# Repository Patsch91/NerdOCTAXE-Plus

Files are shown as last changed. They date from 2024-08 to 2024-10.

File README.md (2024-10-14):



The NerdOCTAXE+ is a 8-Asic version of the [NerdQAxe+](https://github.com/shufps/qaxe) with [Nerdminer](https://github.com/BitMaker-hub/NerdMiner_v2) / [Nerdaxe](https://github.com/BitMaker-hub/NerdAxeUltra) Display and is running the [BitAxe](https://github.com/skot/bitaxe) Firmware as its Core.

It runs standalone and uses 8 ASICs of type BM1368 to achieve an average Hashrate of ~5Th/s at ~100Watts (approx. 110Watt at the wall... i have not measured it yet)



Highlights:

- uses the NerdAxe / NerdMiner display
- 3-Phase Buck  // The TPS could handle 4 Phases... currently thinking of changing it to 4-Phase design
- Standalone, no Raspberry Pi or other PC needed
- AxeOS with improvements and enhancements - slightly modified version of [ESP-Miner-NerdQAxe+](https://github.com/shufps/ESP-Miner-NerdQAxePlus)
  - Influx DB support
  - Better charting (10m, 1h, 1d), data doesn't get lost on Web UI reloads 
  - ASIC clock and voltage adjustable without reboot
  - Stratum client stability improvements (TCP timeouts)

The NerdOCTAXE+ runs with a modified version of the AxeOS: https://github.com/Patsch91/ESP-Miner-NerdOctaxePlus 

-------------------------------

# Build

**DISCLAIMER:** This device is an *advanced* build and partly WIP. To get 8 Asics soldered properly *can* be very hard and frustrating if you are not used to soldering Asics or soldering in general. Using that amount of power, this device isn't a toy and you should know what you are doing - stay safe!

The first prototype is running a little bit high on Temps: Buck at ~80°C and Asics about 60-70°C (so for now I used a rather unconventional way of additional cooling glueing some -many- cheapo small heatsinks directly onto the PCB which dropped the buck Temp to nice 50°C and Asics about 50-60°C)

**PCB:** For example with the JLC Plugin for Kicad you can export the files out of Kicad to order directly from JLCPCB or any other PCB-Manufacturer

**BOM:** You can directly upload the .csv in this repo to Digikey (watch out - this is still a bit of WIP - you could delete the heatsink for example, which is actually in the BOM, but I am currently testing other ones which I will add later on). You will have to order the Lilygo T-Display S3 seperately.

**HEATSINKS:** Cooling is WIP. For the actual first Prototype I used 2 aluminium heatsinks in 60x60x36mm. These are sufficient but I think I can find better ones - again cooling is still a bit WIP.

**FANS:** I started with 2x Noctua 80mm PWM Fans but they were not powerful enough to cool this device enough in combination with the mentioned 60mm heatsinks. So I am now using 2x Arctic S8038-7K (Monsters :P).  I am currently running this miner with Fan-PWM set to 35%. This is enough to keep the buck at about 50°C and asics ~50-60°C.  (!!Note: These Fans have a relatively high "starting current" - so make sure you dont change the fan-pwm upwards in steps too big... for example the miner running hot with Fan-PWM at ~10% (pulling more amps as the Asics getting hot) turning the Fan-PWM up to 90% in one step *could* lead to triggering the Fuse as the fans are pulling heavy to "accelerate")

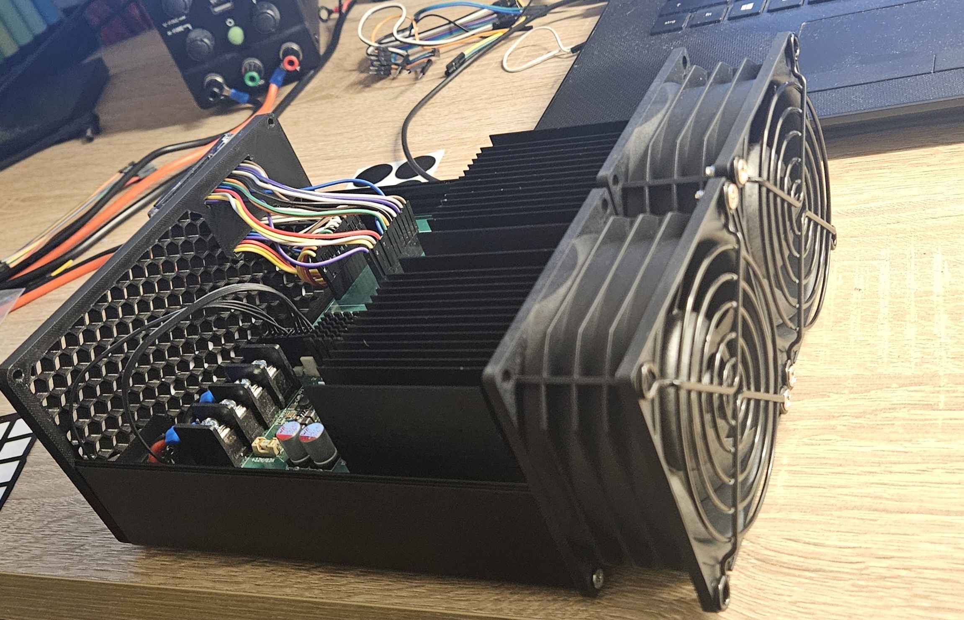
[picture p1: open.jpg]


**CASE** I used a 80x160mm Aluminium-Case which can be found in various lengths on Amazon/ebay/aliexpress etc.

**BACKPLATE** Step files will be provided soon. Will make some changes to integrate the T-Display better into the Backplate :) I used this [XT60 Terminals](https://www.amazon.de/VUNIVERSUM-XT60BE-F-Einbaustecker-Wassergesch%C3%BCtzt-Goldstecker/dp/B0BY5SSBNL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) integrated in the Backplate.

-------------------------------

Current developments:
====
10/14/24: The "bigger heatsink" test-pcb is coming soon. Changed the 4-Layer PCB to 6-Layer to conquer the heavy load on the rather small 1V2-Zone and added a whole 1V2 Layer + GND Layer. This should reduce the PCB-Temperatures, the Buck Temperature as it is located near the "hot" area and the voltage drop between the buck and the Asic Input. This design should be a little more energy efficient - I guess just some %´s, but should be noticable. 

Misc
====
If you like this project and want to support future work, feel free to donate to:
**`bc1q0ctaxeha3lpsaaz7kpjulflw2d9p66fhkp48dk`**

or related projects without which this project would not have been possible for me:

[Nerdaxe](https://github.com/BitMaker-hub/NerdAxeUltra)

[NerdQAxe+](https://github.com/shufps/qaxe)

[OSMU](https://osmu.wiki/)

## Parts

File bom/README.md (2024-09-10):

***BOM***

---------------------

Lilygo T-Display S3
-------

The Lilygo T-Display is *not* included in this csv. You will have to order it seperately - If you order the T-Display with the pins already soldered on you can of course delete the male pin header from this BOM. To connect the Board with the Screen I used Dupont Jumpers in 10cm. You just need these when you are building the setup with the case and the backplate.

Fuse
-------

In the "octaxe+DK wFuseHolder" there is - as the name indicates - a FuseHolder with a 10A Fuse. The 10 Amps should be sufficient when properly cooled. My prototype draws between 8,2 - 9,0A (Could be more when you power the Fans up to higher speeds) Maybe you should get some additional 12A Fuses (F2592CT-ND) in case 10A are blowing to early.

Heatsinks
-------

In the actual BOM you could delete the small heatsink too (Partno: "501100B00000G-ND") I have used 9x9x12mm Heatsinks instead, they fit quite nice on the Mosfets. In addition to that, to cool the buckconverter even more I used some 14x14x13mm small heatsinks on the backside of the pcb under the Buck. So with this setup it runs at about 55°C.

For cooling the Asics my first try were two heatsinks in 60x60mm with 39mm in height. These are pretty cheap on amazon, aliexpress etc. They are capable of cooling the 8 Asics but you need to turn the Fans up a bit :) As they are coming without any mounting helpings you will have to drill the holes yourself.
In the "bigger heatsink" branch I am currently trying to implement the heatsink from an Fujitsu RX2540 M1/M2. These ones are cheap aswell but you wont have to drill them by yourself... but this is actually WIP

Fans
-------

I used two Arctic S8038-7K Fans. Tried Noctua 80mm too, but with my heatsink configuration they were not powerful enough to get this miner to an acceptable temperature.

Case
-------

To have everything closed up I used a 80x160mm aluminium pcb junction box. These are widely available on amazon/aliexpress etc. I bought this [Case](https://www.amazon.de/dp/B08BLTBY2Q?ref=ppx_yo2ov_dt_b_fed_asin_title)  in 170mm lenght. For the "bigger heatsink" variant you should at least go for 220mm lenght.

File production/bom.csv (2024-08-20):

Designator | Footprint | Quantity | Value | LCSC Part #
_3, _2, |  | 3
C1 | 0805 | 1 | 2.2n
C10, C11, C176 | 0805 | 3 | 100n/0.7mm
C100 | 0805 | 1 | 10µ/25V
C101, C102, C103, C107, C139, C14, C140, C16, C167, C168, C178, C25, C53, C55, C74, C75, C82, C83, C87, C88, C96 | 0805 | 21 | 100n
C104 | 0805 | 1 | 10n
C105, C108, C121, C122, C123, C124, C125, C126, C127, C128, C129, C130, C131, C133, C135, C136, C137, C138, C141, C143, C144, C145, C146, C147, C148, C149, C150, C151, C152, C153, C154, C155, C156, C157, C158, C159, C161, C163, C164, C165, C166, C169, C171, C172, C173, C174, C175, C195, C196, C197, C203, C204, C205, C211, C212, C213, C219, C220, C221, C26, C27, C28, C29, C30, C31, C32, C33, C34, C35, C36, C37, C38, C40, C41, C42, C43, C44, C46, C47, C49, C50, C51, C52, C54, C56, C57, C58, C6, C60, C61, C62, C63, C65, C66, C67, C69, C70, C71, C72, C73, C76, C78, C79, C8, C80, C85, C93, C94 | 0805 | 108 | 1µ
C106 | 1206 | 1 | 22µ/16V
C109, C110, C179, C18, C180, C19 | 0805 | 6 | 1n/0.7mm
C111, C191, C192, C193, C20, C23, C45, C81, C89 | 1210 | 9 | 22µ/25V
C112, C117, C181 | 0805 | 3 | 3.3n/25V
C113, C118, C182 | 0805 | 3 | 1µ/25V
C114, C115, C116 | 0603 | 3 | 22p
C119, C120, C132, C134, C15, C160, C162, C17, C183, C64, C68 | 0805 | 11 | 10µ
C12, C13, C177 | 0805 | 3 | 2.2µ
C142, C170, C184, C185, C21, C22, C24, C39, C59, C77 | 1210 | 10 | 100µ/6.3V
C186, C187, C188, C189, C194, C48, C84, C86, C90, C91, C95, C97, C98, C99 | 1210 | 14 | 330µ/4V
C190, C92 | CP_Elec_8x10 | 2 | 220µ/25V
C2, C4, C9 | 0805 | 3 | 1n
C3 | 0603 | 1 | 12p
C5 | 0805 | 1 | 330n
C7 | 0805 | 1 | 4.7µ
D1 | D_SMB | 1 | SMBJ12A
D2 | D_SOD-128 | 1 | PMEG4030EP,115
D3 | D_SOD-123 | 1 | 1N5819
F1 | fuseholder_littlefuse_blok | 1 | 12A
J1 | Barrier Terminal 01x04 | 1 | Conn_01x04
L1, L2, L4 | IFLR-4031GC-01-8x10 | 3 | 220nH
L3 | L_Taiyo-Yuden_NR-50xx | 1 | 4.7µH/2.3A/2.7A
M1, M2 | FanPinHeader_1x04_P2.54mm_Vertical | 2 | Fan_4pin
R1 | 0805 | 1 | 16.5k
R10, R15, R17, R20, R22, R31, R36, R37, R38, R41, R43, R46, R8 | 0805 | 13 | 10k
R11, R18, R23, R44, R49, R50, R51 | 0805 | 7 | 2k
R12, R13 | 0805 | 2 | 2.2R/0.5W
R14, R16, R19, R21, R24, R42, R45, R9 | 0805 | 8 | 1k
R2 | 0805 | 1 | 24.3k
R25, R26, R27, R28, R47, R48 | 0805 | 6 | 1R/0.5W
R29, R30 | 0805 | 2 | 0
R3 | 0805 | 1 | 66.5k
R32 | 0805 | 1 | 84.5k
R33, R35 | 0805 | 2 | 2.7k
R34 | 0805 | 1 | 16.2k
R39, R40 | 0805 | 2 | 100
R4 | 0805 | 1 | 100k
R5 | 0805 | 1 | 121k
R6 | 0805 | 1 | 8.06k
R7 | 0805 | 1 | 2.55k
U10, U11, U12, U13, U14, U15, U2, U9 | bm1368-package-modified | 8 | BM1368_mode1
U16, U4, U5 | CSD95472-SON-5x6 | 3 | CSD95472Q5MC
U3 | Texas_RHA0040B_VQFN-40-1EP_6x6mm_P0.5mm_EP4.15x4.15mm_ThermalVias | 1 | TPS53647
U30 | T-Display-S3 | 1 | T-Display-S3
U32 | MSOP-10_3x3mm_P0.5mm | 1 | EMC2302-1
U33 | VSSOP-8_2.3x2mm_P0.5mm | 1 | TXU0102-DCU
U35 | TSSOP-14-1EP_4.4x5mm_P0.65mm | 1 | TXU0304PW
U36 | SOT-23-5 | 1 | MCP1824T-1802E
U37, U38 | TMP1075-DRL | 2 | TMP1075
U6 | SOT-23-6 | 1 | AP3211
U7 | SOT-23-5 | 1 | MCP1824T-0802E
U8 | Oscillator_SMD_EuroQuartz_XO32-4Pin_3.2x2.5mm | 1 | 25MHz

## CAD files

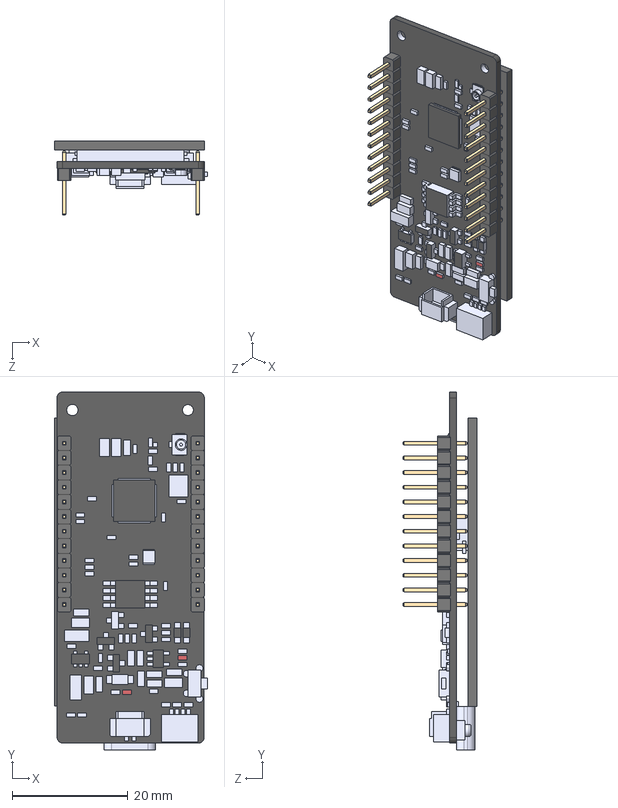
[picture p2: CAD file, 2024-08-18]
3d/T-Display-S3.STEP
26.5 x 62.0 x 12.9 mm
MainBoard_3D
Ecran
1_Male_Pin_2.54_mm x 24

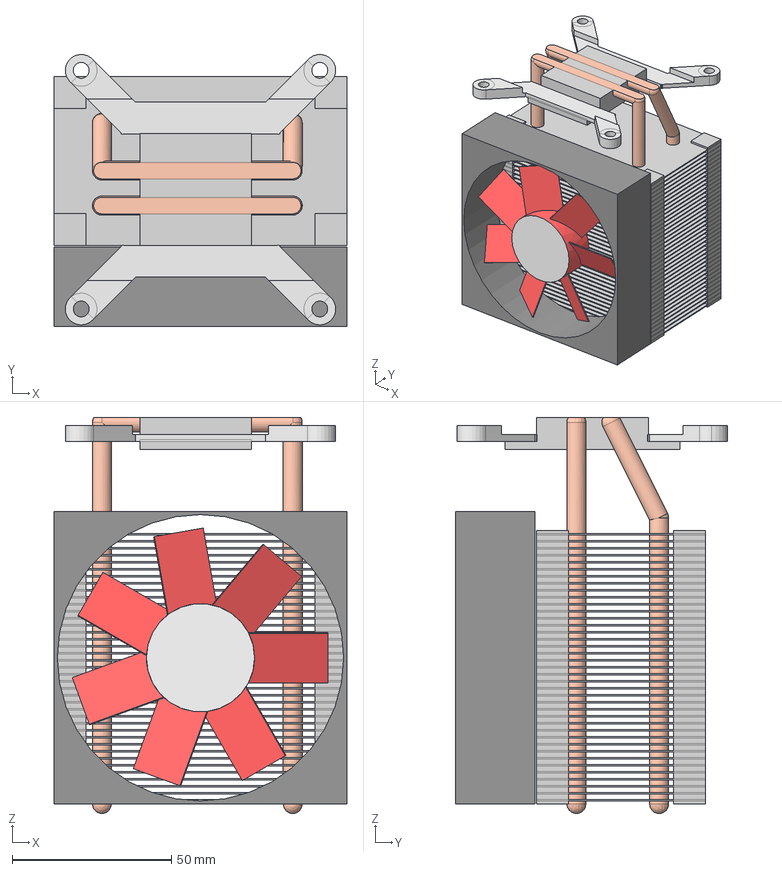
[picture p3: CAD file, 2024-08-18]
3d/lga115x.step
92.0 x 85.5 x 124.5 mm

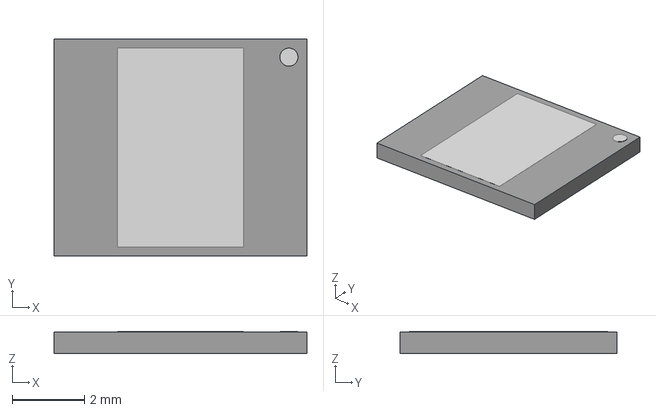
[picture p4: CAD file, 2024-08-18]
3d/bm1366.step
7.00 x 6.00 x 0.61 mm

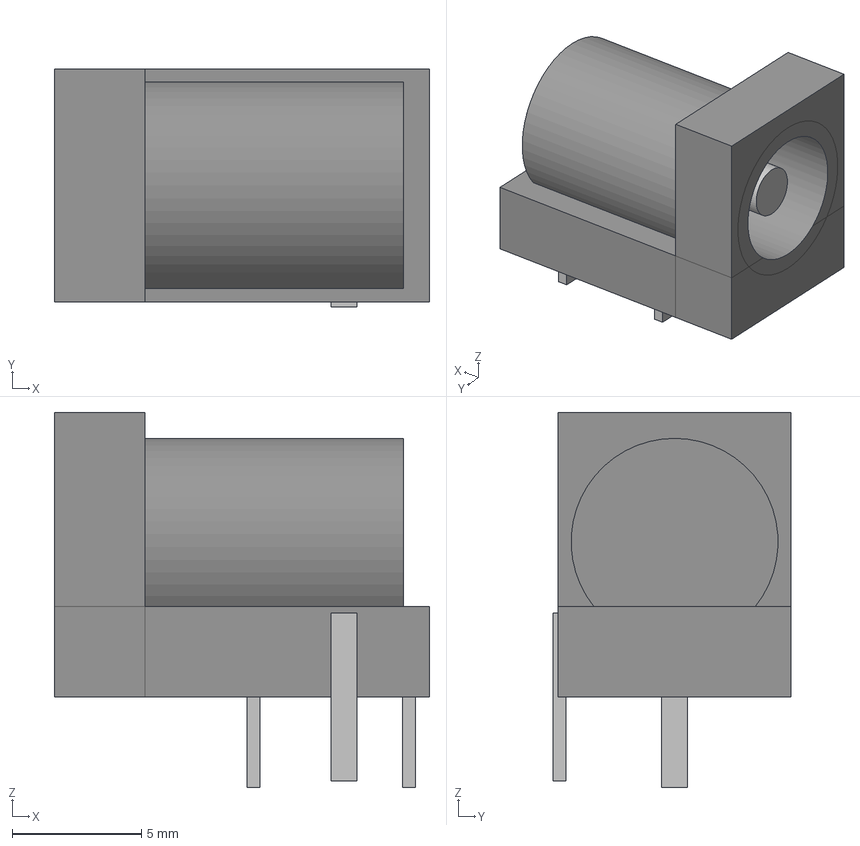
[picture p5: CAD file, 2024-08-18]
3d/barrel-jack.step
14.5 x 9.20 x 14.5 mm

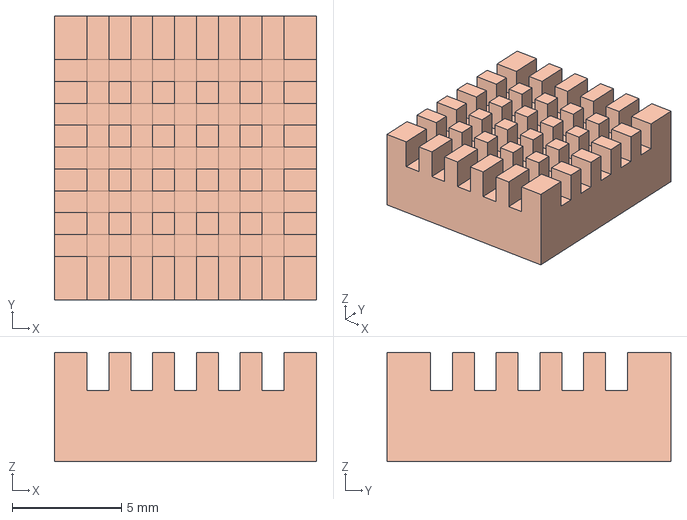
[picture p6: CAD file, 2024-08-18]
3d/heatsink-13x12x5.step
12.0 x 13.0 x 5.00 mm

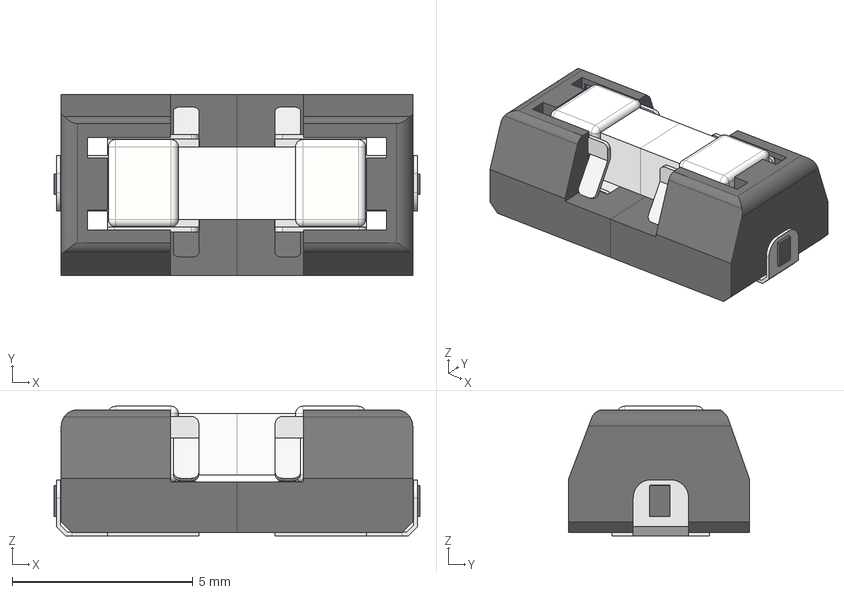
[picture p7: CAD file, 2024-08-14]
3d/Littelfuse 0154.500DRT without value_black v2.step
10.1 x 5.00 x 3.59 mm
Komponente1
Komponente2
Komponente3
Komponente4

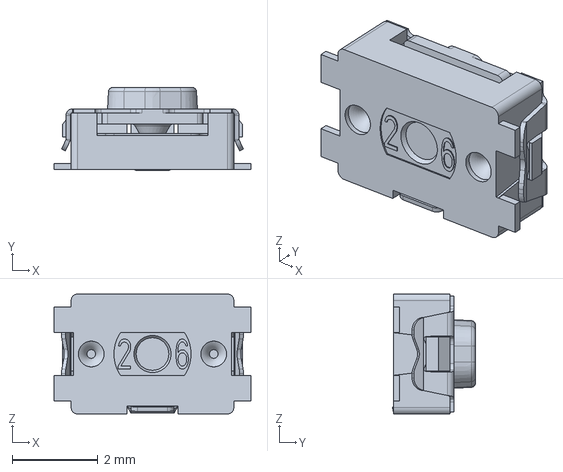
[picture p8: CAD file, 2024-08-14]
3d/KMR231GLFS.stp
4.60 x 1.94 x 2.80 mm

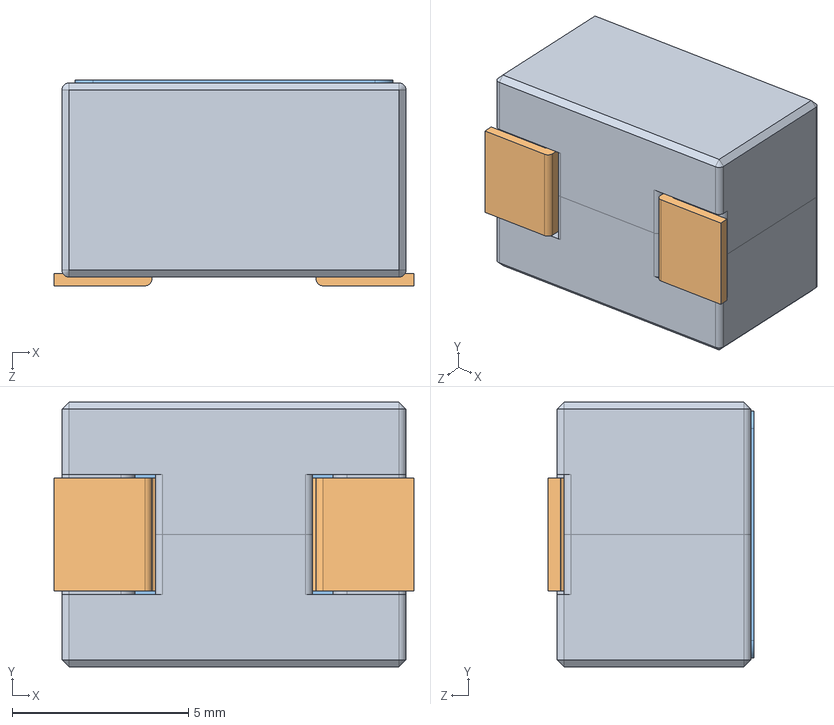
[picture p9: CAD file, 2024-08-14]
3d/FP1006V2-R.STEP
10.2 x 7.50 x 5.83 mm
11150900A x 2
53134900A
Label for FP1006V2-R

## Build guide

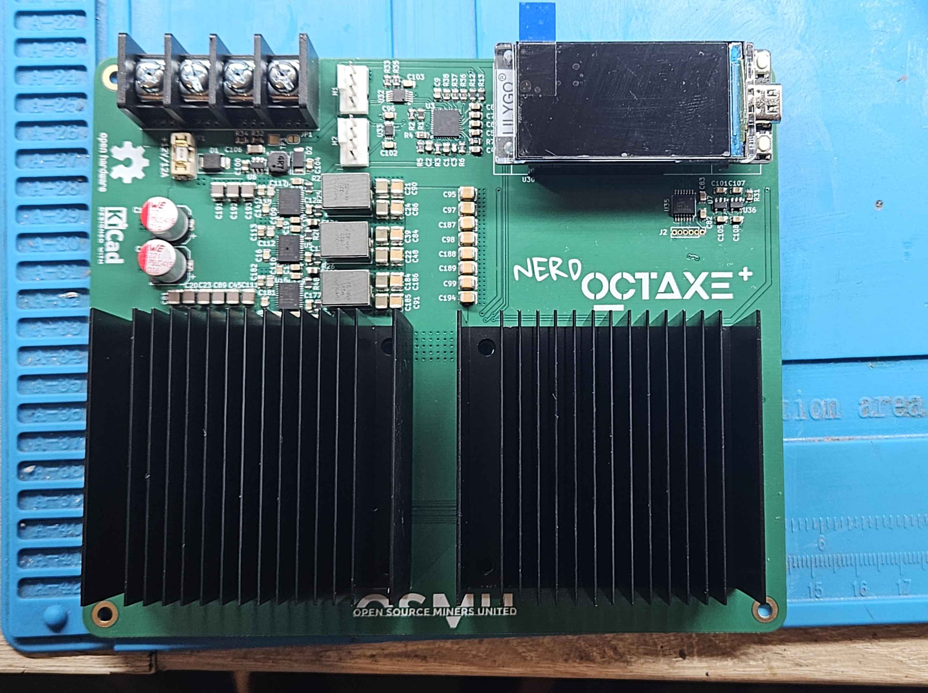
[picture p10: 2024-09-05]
PCB-assembled.jpg

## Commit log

2024-08-18 Net Changes
    Net changes
    [power.kicad_sch]
2024-08-18 Maulwurfspiel
    brainfreeeeze
    [BM1368-1.kicad_sch, BM1368-2.kicad_sch, BM1368-3.kicad_sch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]
2024-08-18 DRC Check
    [BM1368-1.kicad_sch, BM1368-2.kicad_sch, BM1368-3.kicad_sch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]
2024-08-18 DRC strikes back
    [BM1368.kicad_sch]
2024-08-18 References and Logos
    [BM1368-1.kicad_sch, BM1368-2.kicad_sch, BM1368-3.kicad_sch]
2024-08-19 Layout improvements
    GND Plane Layer 3
    Moving Temp-Sensor
2024-08-20 Add Bom
    Added iBom / DK-Bom / JLCProduction files
    [Nerd0catxe+DK-BOM.csv, Nerd8.kicad_sch, bom.csv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]
2024-09-09 Changed Fuse to 10A with Fuseholder
    Fuse in Bom with FuseHolder
    [Nerd8.kicad_sch, octaxe+DK wFuseHolder.csv]
